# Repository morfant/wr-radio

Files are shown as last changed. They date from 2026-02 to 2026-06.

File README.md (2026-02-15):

# WR-Radio

## 설정 방법

### 1. 첫 실행
```bash
python3 wr-radio.py
```
첫 실행 시 `config.json` 파일이 자동 생성됩니다.

### 2. 스테이션 추가/변경
```bash
nano ~/wr-radio/config.json
```
```json
{
  "stations": [
    {
      "name": "내가 좋아하는 라디오",
      "url": "http://stream-url.mp3",
      "location": "Seoul, Korea",
      "lat": 37.5665,
      "lon": 126.9780,
      "color": [255, 100, 100]
    }
  ]
}
```

### 3. 날씨 기능 (선택)
1. https://openweathermap.org/appid 에서 무료 API 키 발급
2. `config.json`에 키 입력:
```json
   {
     "openweather_api_key": "여기에_키_입력"
   }
```

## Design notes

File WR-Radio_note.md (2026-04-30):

# WR-Radio 설계노트

## 프로젝트 개요
- **목적**: 전 세계 환경음을 스트리밍하는 휴대용 인터넷 라디오
- **핵심 하드웨어**: Raspberry Pi Zero 2W, ST7789 240×240 LCD, UDA1334A I2S DAC, PAM8403 앰프, ADS1115 ADC, 로터리 인코더
- **스트리밍 채널**: 제주, 런던, 뉴욕, 캘리포니아, 후지산 (5개 채널)
- **프로토타입 수량**: 약 5대

---

## 전원 시스템

### 아키텍처: TP4056 + TPS61023 분리 구성
```
USB-C → [TP4056] → LiPo 배터리 (2000~3000mAh)
                         │
                    [OUT+/OUT-]
                         │
                    [TPS61023 VIN] → 5V OUT → Pi 5V
                         │
                    EN 핀 ← 슬라이드 스위치 (GND 연결/해제)
```

- TP4056 OUT 단자 사용 (BAT+ 직결 아님) → DW01 과방전 보호 커버
- TPS61023: 3A 출력, Pi 부팅 피크 전류 헤드룸 충분
- USB 핫스왑 드롭아웃 없음 확인 (throttled=0x0)
- 슈퍼캡 불필요 (LiPo Rider Plus 때와 달리 드롭아웃 자체가 없음)

### MP2639A 불채택 사유
- TP4056로 이미 전체 검증 완료
- 1A 충전이면 야간 충전 사용 패턴에 충분
- 추가 복잡도 대비 이득 없음

### 전원 제어
- **슬라이드 스위치**: TPS61023 EN 핀을 GND에 연결/해제
- **택트 스위치**: 설계에서 제거됨 (슬라이드 스위치 단독 운용)
- **Sleep/Wake**: 제거됨 — overlayfs로 안전한 하드 전원 차단 가능

### 배터리 모니터링 (ADS1115)
- **A0**: 배터리 전압 — TPS61023 VIN에서 10kΩ/10kΩ 분압 → 소프트웨어 ×2 보정
- **A1**: VBUS 감지 — TP4056 USB VBUS 패드에서 10kΩ/10kΩ 분압
- 충전 상태 판별:
  - VBUS 있음 + BAT < 4.2V → 충전 중
  - VBUS 있음 + BAT ≈ 4.2V → 충전 완료
  - VBUS 없음 → 배터리 구동 중
- ADS1015 (12비트) 도 이 용도에는 충분 — 차기 리비전에서 비용 절감 가능

---

## PCB 설계 (Eagle CAD / Fusion 360 Electronics)

### 형태
- Pi Zero 2W와 수평 배치 (적층 아닌 옆으로 나란히)
- Pi 쪽: 직각 male 핀헤더
- PCB 쪽: 직각 female 소켓 (2x20 right angle female header)

### 높이 축소 계획
- **로우 프로파일 헤더 소켓 주문**: PH3.5mm (일반 PH8.5 대비 5mm 절감)
  - E-Simpo 1x40핀, AliExpress 주문 완료
  - 매칭 male 헤더: PH7.5mm 주문 완료
- 모듈 스태킹 검토 중 (UDA 아래 PAM8403 등) — 발열/노이즈 주의 필요

### 그라운드 설계
- 바텀 레이어: GND 폴리곤 (3개 그룹 분할)
- 탑 레이어: 여분 공간 GND 구리 푸어
- Star grounding: 아날로그/디지털 GND 한 점 합류

### 디커플링 캐패시터 (최종 목록)
- 각 모듈 VIN-GND: 100nF 세라믹 (대부분 모듈 내부 디커플링 있으므로 보험용)
- 3.3V GPIO 헤더 근처: 100nF + 10µF
- 로터리 인코더 S1/S2: 100nF 각각 (소프트웨어 디바운싱 충분하면 생략 가능)

---

## PCB 프로토타입 테스트 결과 (2026-04-30)

### ✅ 정상 동작 확인
- LCD (ST7789) 정상 표시
- 배터리 전압 모니터링 (ADS1115 A0) 정상
- VBUS 충전 상태 감지 (ADS1115 A1) 정상
- BLE 오디오 스트리밍 정상
- GND-5V 간 쇼트 없음 (캐패시터 충전으로 인한 일시적 도통만 확인 — 정상)

### ❌ BCLK 배선 오류 발견 및 수정
- **문제**: I2S BCLK가 GPIO 15에 연결됨 (정상: GPIO 18)
- **원인**: PCB 설계 시 핀 배정 오류
- **임시 수정**: 커터칼로 GPIO 15→UDA1334A BCLK 트레이스 절단, GPIO 18에서 점퍼 와이어로 연결
- **결과**: UDA1334A 오디오 출력 정상 동작
- **다음 리비전**: PCB에서 BCLK를 GPIO 18로 수정 필수
- **교훈**: Pi I2S 핀은 하드웨어 고정 — BCLK=GPIO18, LRCLK=GPIO19, DIN=GPIO21, 소프트웨어로 변경 불가

### 🔊 스피커 노이즈 분석
두 가지 노이즈 원인 확인:

**1. PAM8403 자체 노이즈 (Class-D 스위칭)**
- 이어폰 잭: 깨끗함
- 스피커: 저볼륨/무음 시 노이즈 들림, 스트리밍 중에는 묻힘
- 원인: PAM8403 고정 24dB 게인이 플로어 노이즈 증폭
- 분압 저항 기존 설치되어 있으나 불충분
- 소프트웨어 볼륨 낮추기로는 해결 불가 (앰프 자체 노이즈이므로)
- **대응**: 프로토타입에서는 감수, 차기 리비전에서 MAX98357A (I2S 직결 앰프) 교체 검토

**2. LCD SPI 노이즈**
- LCD 업데이트 시 "디기딕" 하는 추가 노이즈 발생
- SPI 고주파 노이즈가 전원 라인을 통해 오디오 쪽으로 전달
- **수정**: 메인 5V와 LCD VCC 사이에 **페라이트 비드** 직렬 삽입
  ```
  메인 5V ── [페라이트비드] ── 100nF캡 ── LCD VCC
                                  |
                                 GND
  ```
- 페라이트 비드 사양: 100Ω @ 100MHz, 정격전류 500mA 이상
- **결과**: 완전히 잡히진 않았지만 개선 효과 있음 확인
- **다음 리비전**: PCB에 페라이트 비드 정식 포함

### 기타 참고
- 다른 Pi에 기존 SD카드 이동 시 PulseAudio 캐시 충돌 가능
  - `rm -rf ~/.config/pulse && pulseaudio -k && pulseaudio --start` 로 해결
- `amixer contents` 빈 출력은 정상 (UDA1334A에 하드웨어 볼륨 컨트롤 없음)

---

## 소프트웨어

### 아키텍처
- Python 모듈 구조: main.py, display.py, player.py, config.py, state.py, input.py
- 오디오: mpv (스트리밍), BlueZ + PulseAudio (Bluetooth)
- WiFi: NetworkManager / nmcli (cloud-init/netplan에서 이전 완료)
- 디스플레이: SPI 16MHz (64MHz에서 노이즈로 인해 하향)

### 부팅 최적화
- cloud-init, ModemManager 비활성화
- 39초 → 34초로 단축
- 스플래시 이미지 + systemd 서비스 구현

### UI
- 로터리 인코더: 짧게 누르기 = 볼륨 모드, 길게 누르기 = 밝기 모드
- LCD 업데이트: 부분 화면 렌더링 (region-specific update)
- 날씨 아이콘: PIL 커스텀 드로잉 (이모지 폰트 호환 문제 해결)

---

## SD카드 보호: overlayfs (배포판 적용 예정)

- 루트 파일시스템을 읽기 전용 마운트, 변경사항은 RAM에만 기록
- 전원 갑자기 끊어도 SD카드 손상 없음
- 영구 저장 항목 (별도 `/data` 파티션): config.json, Bluetooth 페어링 정보
- 개발 중에는 OFF, 배포판 최종 이미지에서 ON

---

## 케이스 (Fusion 360)

- 파라메트릭 Python 스크립트로 자동 생성
- 보스, 리브, 마운팅 시스템, 컴포넌트별 컷아웃 포함
- 대형 배터리 + 스피커 레이아웃 최적화 중

---

## 스피커 현황

- 현재: 102mm 4Ω — 저음 왜곡 + SPI 노이즈 (PCB 이후 재평가)
- 검토 중: 30mm 캡슐 스피커, 익사이터(surface transducer)

---

## 주요 학습 사항

- 브레이크아웃 모듈은 내부 디커플링 포함 — 외부 추가는 보험용
- SPI 64MHz 노이즈가 전원/GND를 오염 → 16MHz 하향 + LCD VCC 캡 + 페라이트 비드로 완화
- PAM8403 고정 24dB 게인 → 입력 어테뉴에이션 또는 앰프 교체 필요
- UDA1334A는 라인 레벨 출력 → 이어폰 직결은 기능하지만 최적은 아님
- LCD update를 인코더 인터럽트 핸들러 안에서 하면 타이밍 간섭 → 디바운스 분리 필요
- LiPo 최적 범위 20~80%, 완전 방전 후 충전은 NiCd 시대 미신
- Pi I2S 핀은 SoC 하드웨어 고정: BCLK=GPIO18, LRCLK=GPIO19, DIN=GPIO21 — 변경 불가

---

## 향후 계획

- [x] TP4056 + TPS61023 브레드보드 검증 완료
- [x] USB 핫스왑 드롭아웃 없음 확인
- [x] 전체 부하 테스트 (Pi + DAC + 앰프 + LCD) 완료
- [x] ADS1115 배터리 전압 + VBUS 감지 구현
- [x] 부팅 시간 최적화 (39초 → 34초)
- [x] 스플래시 이미지 + systemd 서비스 구현
- [x] PCB Rev.1 제작 및 기본 동작 확인
- [x] BCLK 배선 오류 발견 및 점퍼 와이어 수정
- [x] SPI 노이즈 완화: 페라이트 비드 삽입 테스트
- [ ] **PCB Rev.2 설계** — BCLK→GPIO18 수정, 페라이트 비드 정식 포함
- [ ] 로우 프로파일 헤더 입고 후 높이 테스트 (PH3.5 소켓 + PH7.5 핀)
- [ ] 스피커 선정 확정 (PCB 이후 노이즈 재평가)
- [ ] 케이스 최종 설계 완성 + 출력
- [ ] overlayfs 설정 (배포판 단계)
- [ ] SD카드 이미지 배포판 제작 (의존성 포함)
- [ ] 사용자용 설정 가이드 문서화
- [ ] Bluetooth 헤드폰 지원 (선택적 확장)
- [ ] 마이크 입력 / 필드 레코딩 (장기)
- [ ] 앰프 교체 검토: MAX98357A (I2S 직결, UDA1334A+PAM8403 대체 가능)

---

## 주요 부품 공급처

- 디바이스마트, 아이씨뱅큐 (국내)
- Adafruit, AliExpress (해외)
- 로우 프로파일 헤더: AliExpress E-Simpo

---

*최종 업데이트: 2026-04-30 (PCB Rev.1 테스트: BCLK 배선 오류 수정, SPI 노이즈 페라이트 비드 완화, PAM8403 자체 노이즈 확인, 로우 프로파일 헤더 주문)*

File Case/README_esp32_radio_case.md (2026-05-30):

# ESP32 Portable Radio Case (Standard) — OpenSCAD

This folder contains a **parametric OpenSCAD** model for a two-part portable enclosure:
- **Base**
- **Lid (front panel)**
- **Battery door** (rear)

## Default Target
- 150 × 90 × 50 mm outer size
- 50 mm speaker (front grill)
- 0.96" OLED (SSD1306) window (toggle to 1.8" TFT if needed)
- Rotary encoder on the front
- 3.5 mm jack on the right
- Power switch on the left
- Micro‑USB slot on the back (optional toggle)
- Internal bosses/standoffs for ESP32 and small DAC/AMP boards
- Battery door fits typical 4×AA (2×2) holder

## How to Use
1. Install **OpenSCAD**.
2. Open `esp32_radio_case.scad`.
3. At the top, set `show_part` to `"base"`, render (F6), then `File → Export → STL`.
4. Repeat with `"lid"` and `"door"`.
5. Print each STL. Suggested: PETG/ABS, 0.2 mm layer, 15–25% infill, ≥3 perimeters.

## Adjustments
- Edit the **Parameters** section to match your exact modules:
  - `spk_d`, `oled_win`/`tft_win`, `enc_hole_d`, `jack_hole_d`, etc.
  - Positions: `spk_pos`, `oled_pos`/`tft_pos`, `enc_pos`, side cutouts, etc.
- Corner bosses accept **M3** (inserts or self-tapping). 
  - Hole defaults: `m3_hole` (clearance in lid), `m3_pilot` (pilot in base boss).

## Notes
- The *speaker grill* is a perforated hole pattern. Adjust `hole_r`/spacing inside `drill_grill()`.
- The **battery door** is a simple plate; you can tape/magnetize or add a tiny screw if desired.
- The file includes a basic **USB cutout**; set `usb_on_back=false` to remove.

## Next Steps
- After a first test print, measure your parts and tweak tolerances (`tol`, `lip_tol`).
- If you switch to a **1.8" TFT**, set `use_oled=false` and adjust `tft_win`/`tft_pos`.
- For very tight builds, consider moving to a custom PCB for cable reduction.

Happy printing! 🎧

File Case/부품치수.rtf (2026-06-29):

Lcd
35.5 x 70(ÀÌ Áß 20Àº ÄÉÀÌºí) x 7.5

¿£ÄÚ´õ
Áö¸§ 25 ³ôÀÌ 30(³»ºÎ) + 25(¿ÜºÎ)

½ºÇÇÄ¿
65 x 65 x 27(À¯´Ö µÎ²²)

토글 스위치
(외부 돌출 원통형 6 + 내부 박스 및 케이블 고려 20) x 13 x 7
직경 6.13mm

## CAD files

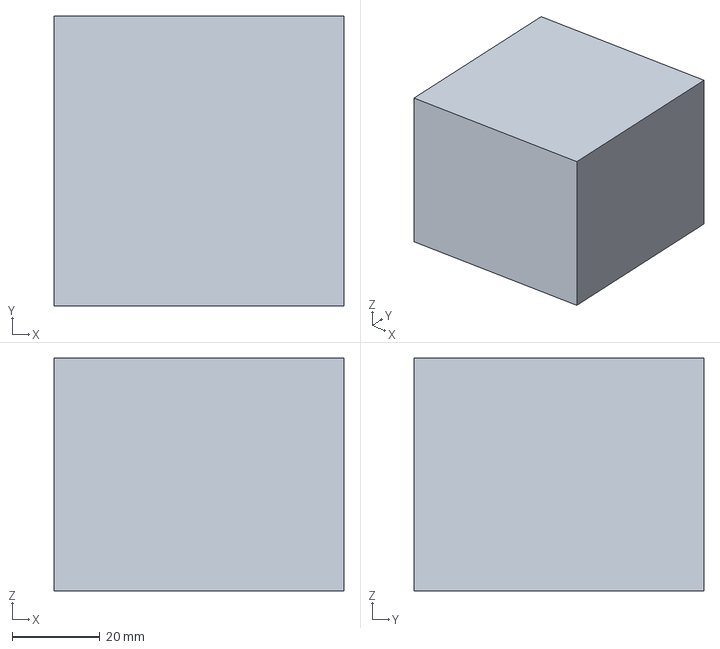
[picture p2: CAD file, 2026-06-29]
Case/envelope_speaker.step
66.0 x 66.0 x 53.0 mm

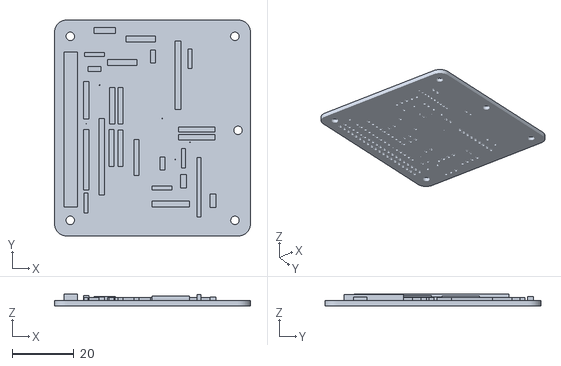
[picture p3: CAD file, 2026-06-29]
Case/radio-hat-v07.stl
63.5 x 70.0 x 3.82

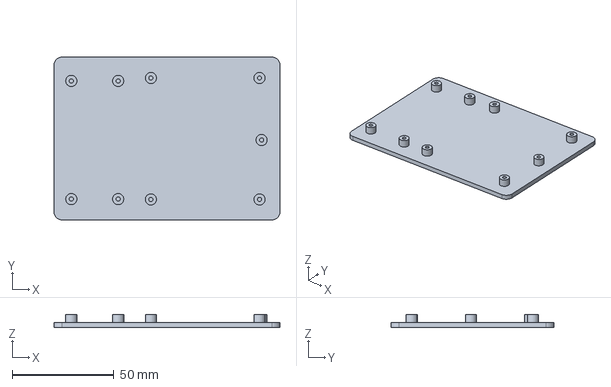
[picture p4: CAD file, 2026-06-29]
Case/wr_radio_base.step
110.9 x 80.0 x 6.50 mm

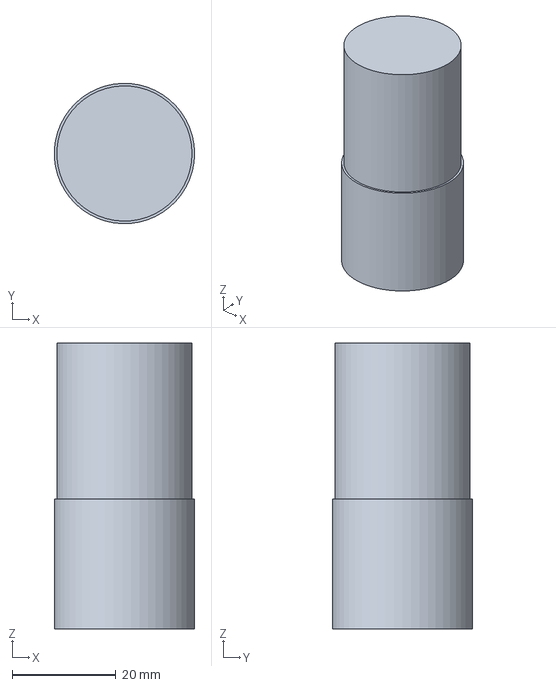
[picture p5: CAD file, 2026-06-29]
Case/envelope_encoder.step
27.0 x 27.0 x 55.0 mm

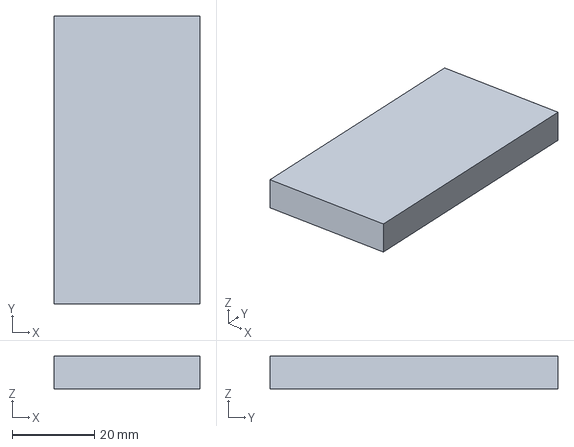
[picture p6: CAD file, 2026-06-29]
Case/envelope_lcd.step
35.5 x 70.0 x 8.00 mm

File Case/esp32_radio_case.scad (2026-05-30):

/*
ESP32 Portable Radio Case (Standard) - OpenSCAD
Author: ChatGPT
Version: 1.0
Units: millimeters

How to use:
1) Open this file in OpenSCAD.
2) Set 'show_part' = "preview" | "base" | "lid".
3) Press F6 (Render) then File → Export → STL for each part.

Printing tips (FDM):
- Material: PETG or ABS/ASA preferred (humidity tolerance). PLA ok indoors.
- Layer: 0.2 mm, walls ≥ 3 perimeters, infill 15–25%.
- No supports needed by default (chamfers/bridges are designed).
- Use heat-set M3 inserts in bosses, or self-tapping M3 screws into pilot holes.

This design targets:
- Enclosure outer size ≈ 150 × 90 × 50 (W×H×D)
- 50 mm speaker (2") front grill
- 0.96" I2C OLED (SSD1306) window OR 1.8" TFT (ST7735) window (toggleable)
- Rotary encoder on front
- 3.5 mm TRS jack on right side (panel-mount style)
- Power toggle on left side (panel cutout)
- Rear battery door (4×AA holder, 2×2 type) with simple slide latch
- Internal standoffs for: ESP32 DevKit, DAC, AMP
- M3 corner posts + lid with M3 screw holes

You may adjust parameters below to fit your exact modules. 
*/

/////////////// PARAMETERS \\\\\\\\\\\\\

show_part = "preview"; // "preview", "base", "lid", "door"

// Overall outer dimensions
W = 150;   // width (x)
H = 90;    // height (y)
D = 50;    // depth (z)

wall = 2.6;        // wall thickness
lip = 1.0;         // lid/base overlap lip
corner_r = 5;      // external fillet radius (visualized via minkowski)

// Fasteners
boss_d = 6.6;      // corner boss OD for M3 inserts/screws
boss_h = 10;       // boss height in lid/base
m3_hole = 3.2;     // through hole size for M3 (clearance)
m3_pilot = 2.6;    // pilot for self-tap (if not using inserts)

// Speaker
spk_d = 50;        // speaker driver outer diameter
spk_depth = 32;    // driver depth allowance
spk_grill_margin = 3; // grill ring margin
spk_pos = [W*0.30, H*0.62]; // (x,y) from lower-left front panel

// Display
use_oled = true;   // true: 0.96" OLED window ; false: 1.8" TFT window
// OLED 0.96" (visible area ~22x11mm, PCB ~27x27); choose window a bit larger
oled_win = [27, 15]; // window opening (w,h)
oled_pos = [W*0.62, H*0.25]; // front panel position of window center

// TFT 1.8" ST7735 option
tft_win  = [36, 46]; // opening (w,h) oriented portrait by default
tft_pos  = [W*0.62, H*0.28];

// Rotary encoder (front)
enc_hole_d = 7.2;                   // shaft/bushing hole
enc_knob_clear = 18;                // visual clearance circle
enc_pos = [W*0.62, H*0.70];         // front panel position

// 3.5mm jack (right side)
jack_hole_d = 6.6;   // panel mount diameter (adjust for your part)
jack_edge_offset = 18; // distance from front panel along X for cutout center
jack_height = H*0.35; // center height from bottom

// Power switch (left side) — simple rectangle slot
sw_slot = [10, 3];                  // opening (w,h)
sw_edge_offset = 25;                // distance from front edge to slot center
sw_height = H*0.2;                  // center height from bottom

// USB access (rear or side) — small rectangular opening (optional)
usb_slot = [13, 7]; // typical micro-USB
usb_on_back = true;
usb_back_offset = [W*0.65, H*0.18]; // center on back panel

// Battery door (rear, for 4×AA 2×2 holder ~60×60×15)
door_size = [70, 70];
door_pos  = [W*0.50, H*0.55];
door_th = 2.0;
door_clearance = 0.4;

// Internal standoffs (example positions)
standoff_h = 8;
standoff_d = 5.5;
esp32_hole = [[15,15],[45,15],[45,45],[15,45]]; // simplistic 4-hole rectangle (adjust to your DevKit!)
dac_pos = [W*0.62, H*0.52];
amp_pos = [W*0.62, H*0.40];

// Tolerances
tol = 0.3;     // general clearance
lip_tol = 0.2; // lip fit


/////////////// UTILS \\\\\\\\\\\\\

module filleted_box(size=[W,H,D], r=corner_r, center=false){
    // cheap fillet by minkowski with sphere; for preview mainly
    minkowski(){
        cube(size - [2*r,2*r,2*r], center=center);
        sphere(r, $fn=32);
    }
}

module screw_boss(h=boss_h, od=boss_d, hole=m3_hole){
    difference(){
        cylinder(h=h, r=od/2, $fn=40);
        translate([0,0,-1]) cylinder(h=h+2, r=hole/2, $fn=30);
    }
}

module grill_honeycomb(w, h, cell=4, t=1.0){
    // simple hex grid by subtracting circles (lightweight approximation)
    for (x=[-w/2+cell/2:cell:w/2-cell/2])
        for (y=[-h/2+cell/2:cell:h/2-cell/2]){
            translate([x,y,0])
                cylinder(h=t+1, r=cell*0.35, $fn=6);
        }
}

// Rounded rectangle 2D
module rrect2d(sz=[20,10], r=2){
    offset(r=r) offset(delta=-r)
        square(sz, center=true);
}

/////////////// BASE & LID \\\\\\\\\\\\\

module enclosure_base(){
    // Outer shell
    difference(){
        filleted_box([W,H,D], corner_r);
        // Hollow
        translate([wall,wall,wall])
            cube([W-2*wall, H-2*wall, D - wall - lip - lip_tol]);
        // Side cutouts (jack right)
        // right wall center at x=W, y=jack_height, z=D/2
        translate([W - wall/2, jack_height, D/2])
            rotate([0,90,0]) cylinder(h=wall+2, r=jack_hole_d/2+tol, $fn=40);

        // left wall power switch slot
        translate([wall/2, sw_height, D/2])
            rotate([0,90,0])
                linear_extrude(height=wall+2)
                    rrect2d([sw_slot[0]+tol, sw_slot[1]+tol], r=1.0);

        // USB slot on back
        if (usb_on_back){
            translate([usb_back_offset[0], H - wall/2, D/2])
                rotate([90,0,0])
                    linear_extrude(height=wall+2)
                        rrect2d([usb_slot[0]+tol, usb_slot[1]+tol], r=1.0);
        }
    }

    // Lip for lid overlap (inner ledge)
    translate([wall+lip_tol, wall+lip_tol, D - wall - lip])
        cube([W-2*(wall+lip_tol), H-2*(wall+lip_tol), lip]);

    // Corner bosses (for screws up from lid, or inserts)
    boss_z = D - wall - lip - boss_h - 1;
    for (px=[10, W-10])
      for (py=[10, H-10])
        translate([px, py, boss_z])
            screw_boss(boss_h, boss_d, m3_pilot);

    // Internal standoffs plateaus (example)
    // ESP32 area
    for (p=esp32_hole){
        translate([p[0], p[1], wall+2])
            cylinder(h=standoff_h, r=standoff_d/2, $fn=30);
    }

    // DAC/AMP shelves (simple pads)
    translate([dac_pos[0]-10, dac_pos[1]-8, wall+2])
        cube([20,16,standoff_h]);
    translate([amp_pos[0]-10, amp_pos[1]-8, wall+2])
        cube([20,16,standoff_h]);

    // Battery pocket (rear) – slight recess
    translate([door_pos[0]-door_size[0]/2, door_pos[1]-door_size[1]/2, wall+2])
        cube([door_size[0], door_size[1], 8]);
}

module enclosure_lid(){
    // Lid plate with outer fillet mimic (slightly smaller to fit)
    difference(){
        filleted_box([W-2*tol, H-2*tol, wall+lip], corner_r);
        // Underside clearance (leave rim that sits on lip)
        translate([wall,wall,0])
            cube([W-2*wall-2*tol, H-2*wall-2*tol, wall+lip]);
    }

    // Front panel features (speaker, display, encoder)
    // We "cut through" from the front face (y-plane), but since lid is a solid,
    // we subtract thin prisms to make openings.

    // Coordinate helper: front face plane at y = (H-2*tol)
    front_y = H/2; // We'll position cuts by translating to the lid and subtracting from a duplicate

    // Create cutouts by overlapping negative volumes
    difference(){
        // Nothing here; we will union cutouts then subtract at the end via separate module
    }

    // Speaker grill (through-holes in lid)
    translate([spk_pos[0], spk_pos[1], (wall+lip)/2])
        difference(){
            // Open circular aperture area
            cylinder(h=wall+lip+2, r=(spk_d/2)+spk_grill_margin, $fn=80, center=true);
            // Fill with small honeycomb voids (subtract from filler to create holes)
        }

    // Cut: actual holes for grill
    translate([spk_pos[0], spk_pos[1], 0])
        drill_grill();

    // Encoder shaft hole
    translate([enc_pos[0], enc_pos[1], -1])
        cylinder(h=wall+lip+2, r=enc_hole_d/2+tol, $fn=40);

    // Display window (choose one)
    if (use_oled){
        translate([oled_pos[0]-oled_win[0]/2, oled_pos[1]-oled_win[1]/2, -1])
            cube([oled_win[0], oled_win[1], wall+lip+2]);
    } else {
        translate([tft_pos[0]-tft_win[0]/2, tft_pos[1]-tft_win[1]/2, -1])
            cube([tft_win[0], tft_win[1], wall+lip+2]);
    }

    // Lid screw holes (match base bosses)
    for (px=[10, W-10])
      for (py=[10, H-10])
        translate([px, py, -1])
            cylinder(h=wall+lip+4, r=m3_hole/2, $fn=24);
}

module drill_grill(){
    // Make a circular cluster of holes for the speaker grill.
    // Simple pattern: radial rings of holes.
    hole_r = 2;           // hole radius
    spacing = 5;
    maxR = spk_d/2 - 4;   // leave inner margin

    for (r=[spacing:spacing:maxR])
        for (a=[0:360/max(6, floor(r/spacing)):360-1]){
            x = r*cos(a);
            y = r*sin(a);
            translate([x,y,-1])
                cylinder(h=wall+lip+4, r=hole_r, $fn=20);
        }
}
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

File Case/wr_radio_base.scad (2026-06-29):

/*
WR-Radio Base Plate (Raspberry Pi Zero 2W + radio-hat-v07) — OpenSCAD
Units: millimeters

Layout (NOT a stacked HAT): the Pi Zero 2W and the radio-hat PCB lie COPLANAR,
side by side, joined by a 90° right-angle 2x20 header. The HAT's GPIO connector
(J1) is on its LEFT edge, so the Pi sits to the LEFT of the HAT.

This file is just the BASE: a flat plate with M2.5 standoff posts under both
boards. Walls / front panel / battery bay come later.

All board dimensions and hole positions are taken from the Gerber/drill output of
PCB/radio-hat-v07_2026-06-06 (drill format METRIC TZ 000.000, FSLAX34Y34).

Usage:
  1) Open in OpenSCAD.
  2) show_part = "preview" to eyeball board alignment, "base" to export.
  3) Verify pi_gap / pi_y_offset against the physical right-angle header, tweak,
     then F6 (Render) -> File > Export > STL.
*/

/////////////// WHAT TO SHOW \\\\\\\\\\\\\

show_part = "preview";   // "preview" | "base"

/////////////// PARAMETERS \\\\\\\\\\\\\

// --- radio HAT (radio-hat-v07), origin at board bottom-left ---
hat_w = 63.48;           // board width  (x)
hat_h = 69.98;           // board height (y)
// 5x M2.5 mounting holes, gerber coords shifted +5.08 in y so board min = (0,0)
HAT_HOLES = [
    [ 5.10,  5.08],
    [58.44,  5.08],
    [ 5.12, 64.68],
    [58.42, 64.68],
    [59.44, 34.24],      // extra hole, right edge mid-height
];

// --- Raspberry Pi Zero 2W ---
pi_long  = 65;           // long edge
pi_short = 30;           // short edge
// Pi is rotated 90° CW so its long edge runs along Y and the GPIO header faces
// the HAT (+x). It is placed to the LEFT of the HAT.
pi_gap      = 7.45;      // gap between Pi right edge and HAT left edge — measured: 7.3 (bottom) / 7.6 (top), avg 7.45
pi_y_offset = 1.75;      // shift Pi along Y to align header with J1 — measured offset ~0.75mm down from 2.5

// derived Pi placement (do not edit; driven by the two params above)
pi_x0 = -(pi_short + pi_gap);   // Pi bounding-box min x
pi_y0 = pi_y_offset;            // Pi bounding-box min y
// Pi M2.5 holes (58x23 pattern, 3.5 mm from each edge) in base coords
PI_HOLES = [
    [pi_x0 + 3.5,  pi_y0 + 3.5],
    [pi_x0 + 3.5,  pi_y0 + 61.5],
    [pi_x0 + 26.5, pi_y0 + 3.5],
    [pi_x0 + 26.5, pi_y0 + 61.5],
];

// --- base plate ---
base_th   = 2.5;         // plate thickness
margin    = 5.0;         // extra plate border beyond board footprints
corner_r  = 4.0;         // base outer fillet
post_h    = 4.0;         // standoff height (lifts boards off the plate)
post_od   = 5.5;         // standoff outer diameter
screw_d   = 2.1;         // pilot hole for M2.5 self-tapping screw (use 2.6 for inserts)
screw_depth = post_h + base_th;   // how deep the pilot goes

$fn = 48;

/////////////// DERIVED EXTENTS \\\\\\\\\\\\\

// footprint bounds across both boards
min_x = pi_x0 - margin;
max_x = hat_w + margin;
min_y = min(0, pi_y0) - margin;
max_y = max(hat_h, pi_y0 + pi_long) + margin;
plate_w = max_x - min_x;
plate_h = max_y - min_y;

/////////////// MODULES \\\\\\\\\\\\\

module rrect(sz, r) {
    offset(r=r) offset(delta=-r) square(sz, center=false);
}

module standoff(pos) {
    translate([pos[0], pos[1], 0]) {
        difference() {
            cylinder(h = base_th + post_h, d = post_od);
            translate([0, 0, base_th + post_h - screw_depth + 0.01])
                cylinder(h = screw_depth, d = screw_d);
        }
    }
}

module base_plate() {
    // plate
    translate([min_x, min_y, 0])
        linear_extrude(base_th)
            rrect([plate_w, plate_h], corner_r);
    // standoffs
    for (p = HAT_HOLES) standoff(p);
    for (p = PI_HOLES)  standoff(p);
}

// --- preview-only board ghosts (sit on top of the standoffs) ---
module hat_ghost() {
    color([0.2, 0.5, 0.9, 0.35])
        translate([0, 0, base_th + post_h])
            linear_extrude(1.6)
                difference() {
                    square([hat_w, hat_h]);
                    for (p = HAT_HOLES) translate(p) circle(d = 2.75);
                }
}

module pi_ghost() {
    color([0.2, 0.8, 0.4, 0.35])
        translate([pi_x0, pi_y0, base_th + post_h])
            linear_extrude(1.6)
                difference() {
                    square([pi_short, pi_long]);
                    for (p = PI_HOLES) translate([p[0]-pi_x0, p[1]-pi_y0]) circle(d = 2.75);
                }
    // GPIO header block on the Pi edge facing the HAT (visual only)
    color([0.1, 0.1, 0.1, 0.5])
        translate([pi_x0 + pi_short - 5, pi_y0 + (pi_long-50.8)/2, base_th + post_h + 1.6])
            cube([5, 50.8, 8.5]);
}

/////////////// OUTPUT \\\\\\\\\\\\\

if (show_part == "base") {
    base_plate();
} else {
    base_plate();
    hat_ghost();
    pi_ghost();
}

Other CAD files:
Case/envelope_encoder.stl
Case/envelope_lcd.stl
Case/envelope_speaker.stl
Case/wr_radio_base.dxf
Case/wr_radio_base.stl

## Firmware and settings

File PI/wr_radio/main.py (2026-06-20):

#!/usr/bin/env python3
# -*- coding: utf-8 -*-

from PIL import ImageDraw, ImageFont
import os
import signal
import sys
import time

import RPi.GPIO as GPIO
import spidev
from PIL import Image

from .state import AppState
from . import config
from .config import setup_config_interactive, save_settings
from . import player
from . import weather
from . import display
from .input import InputConfig, ButtonState, read_rotary, handle_button
from .battery import BatteryMonitor
from . import bluetooth
from . import wifi
from . import webadmin

LOCK_FILE = "/tmp/wr_radio.lock"

# BCM pins
PIN_S1 = 17
PIN_S2 = 27
PIN_KEY = 22

PIN_CS = 26
PIN_DC = 13
PIN_RST = 6
PIN_BL = 12

# 시스템 메뉴 항목
SYSTEM_MENU_ITEMS = [
    {"label": "Brightness",       "action": "brightness"},
    {"label": "Bluetooth",        "action": "bluetooth"},
    {"label": "Manage Stations",  "action": "station_admin"},
    {"label": "WiFi Setup",       "action": "wifi_setup"},
    {"label": "Power Off",        "action": "shutdown"},
    {"label": "Back",             "action": "back"},
]

# 폰트 경로
FONT_PATH = "/usr/share/fonts/truetype/dejavu/DejaVuSans-Bold.ttf"
FONT_PATH_REGULAR = "/usr/share/fonts/truetype/dejavu/DejaVuSans.ttf"


def load_font(size: int, bold: bool = False) -> ImageFont.FreeTypeFont:
    try:
        path = FONT_PATH if bold else FONT_PATH_REGULAR
        return ImageFont.truetype(path, size)
    except Exception:
        return ImageFont.load_default()


def acquire_lock():
    if os.path.exists(LOCK_FILE):
        try:
            with open(LOCK_FILE, "r") as f:
                pid = int((f.read() or "0").strip())
            if pid > 0:
                os.kill(pid, 0)
                print(f"❌ 이미 실행 중입니다 (pid={pid}).")
                sys.exit(1)
        except ProcessLookupError:
            pass
        except Exception:
            pass

    with open(LOCK_FILE, "w") as f:
        f.write(str(os.getpid()))


def release_lock():
    try:
        if os.path.exists(LOCK_FILE):
            os.remove(LOCK_FILE)
    except Exception:
        pass


def pwm_safe_close(state: AppState):
    try:
        if state.pwm_backlight is not None:
            try:
                state.pwm_backlight.stop()
            except Exception:
                pass
            try:
                del state.pwm_backlight
            except Exception:
                pass
    finally:
        state.pwm_backlight = None


def set_brightness(state: AppState, level: int, bl_pin: int) -> int:
    level = max(10, min(100, level))
    if state.pwm_backlight is None:
        state.pwm_backlight = GPIO.PWM(bl_pin, 1000)
        state.pwm_backlight.start(level)
        state.current_brightness = level
        return level
    try:
        state.pwm_backlight.ChangeDutyCycle(level)
        state.current_brightness = level
        return level
    except Exception:
        pwm_safe_close(state)
        state.pwm_backlight = GPIO.PWM(bl_pin, 1000)
        state.pwm_backlight.start(level)
        state.current_brightness = level
        return level


def draw_system_menu(state: AppState, selected_index: int) -> Image.Image:
    """시스템 메뉴 화면 렌더링"""
    img = Image.new("RGB", (240, 240), (0, 0, 0))
    draw = ImageDraw.Draw(img)

    font_title = load_font(13, bold=False)
    font_item  = load_font(15, bold=False)

    # 타이틀
    draw.text((20, 18), "System", fill=(80, 80, 100), font=font_title)
    draw.line([(20, 38), (220, 38)], fill=(40, 40, 50), width=1)

    # 메뉴 항목 — 항목 수에 따라 간격 자동 조정
    n = len(SYSTEM_MENU_ITEMS)
    start_y = 50
    item_h = min(40, (240 - start_y) // n)

    for i, item in enumerate(SYSTEM_MENU_ITEMS):
        y = start_y + i * item_h
        is_selected = (i == selected_index)

        if is_selected:
            draw.rounded_rectangle([(16, y - 1), (224, y + item_h - 3)],
                                   radius=6, fill=(25, 25, 40))
            label_color = (230, 230, 255)
        else:
            label_color = (100, 100, 120)

        draw.text((32, y + max(2, (item_h - 18) // 2)),
                  item["label"], fill=label_color, font=font_item)

    return img


def draw_brightness_menu(state: AppState) -> Image.Image:
    """밝기 조절 화면"""
    img = Image.new("RGB", (240, 240), (0, 0, 0))
    draw = ImageDraw.Draw(img)

    font_title = load_font(13, bold=False)
    font_value = load_font(22, bold=False)

    draw.text((20, 18), "Brightness", fill=(80, 80, 100), font=font_title)
    draw.line([(20, 38), (220, 38)], fill=(40, 40, 50), width=1)
    draw.text((120, 120), f"{state.current_brightness}%", fill=(230, 230, 255), font=font_value, anchor="mm")

    return img


def return_to_normal(state: AppState, gpio_pins: dict, radio_stations: list, current_index: int):
    """시스템 메뉴에서 normal 복귀 시 화면 완전 초기화 후 재렌더"""
    try:
        blank = Image.new("RGB", (240, 240), (0, 0, 0))
        display.display_image(GPIO, {"CS": gpio_pins["CS"], "DC": gpio_pins["DC"]}, state, blank)
    except Exception:
        pass
    wd = weather.get_cached_weather(state, radio_stations[current_index]["lat"], radio_stations[current_index]["lon"])
    display.display_radio_info(GPIO, {"CS": gpio_pins["CS"], "DC": gpio_pins["DC"]}, state, weather_data=wd, force_full=True)
    state.last_displayed_weather = wd


def reload_stations(state: AppState, pins: dict):
    """웹 관리로 변경된 config.json을 메인 스레드에서 안전하게 반영.
    state.radio_stations / current_index는 오직 여기(메인 스레드)서만 수정된다."""
    state.stations_dirty = False   # 먼저 끔: reload 중 들어온 추가 변경은 다음 루프가 처리
    new = config.load_config()
    if not new or not new.get("stations"):
        return
    stations = config.normalize_stations(new["stations"])

    playing_url = None
    if state.is_playing and 0 <= state.current_index < len(state.radio_stations):
        playing_url = state.radio_stations[state.current_index].get("url")

    state.radio_stations = stations

    if playing_url is not None:
        # 재생 중이던 스테이션을 url로 추적 → 앞 항목 삭제/순서변경에도 끊김 없음
        match = next((k for k, s in enumerate(stations)
                      if s.get("url") == playing_url), None)
        if match is not None:
            state.current_index = match
        else:
            # 재생 중이던 스테이션이 삭제/URL변경됨 → 클램프 후 새 스테이션 재생
            state.current_index = max(0, min(state.current_index, len(stations) - 1))
            state.pending_play = True
            state.last_station_change_time = time.time()
    else:
        state.current_index = max(0, min(state.current_index, len(stations) - 1))

    # 화면/날씨 캐시 강제 리프레시
    state.last_displayed_index = -1
    state.last_updated_index = -1
    state.last_displayed_weather = None
    if state.current_mode == "normal":
        return_to_normal(state, pins, state.radio_stations, state.current_index)
    print(f"📻 스테이션 목록 갱신: {len(stations)}개 (현재 {state.current_index + 1})")


def get_admin_url() -> str:
    """관리 페이지 접속 URL. mDNS 호스트명(<host>.local) 우선, 실패 시 라우팅 IP."""
    import socket
    try:
        host = socket.gethostname()
        if host:
            return f"{host}.local:{webadmin.PORT}"
    except Exception:
        pass
    try:
        s = socket.socket(socket.AF_INET, socket.SOCK_DGRAM)
        s.connect(("8.8.8.8", 80))
        ip = s.getsockname()[0]
        s.close()
        return f"{ip}:{webadmin.PORT}"
    except Exception:
        return f"localhost:{webadmin.PORT}"


def show_station_admin(state: AppState, pins: dict):
    """LCD에 관리 페이지 URL을 표시하고 노브를 누르면 종료.
    웹서버는 상시 동작하므로 이 화면은 단순히 주소 안내용이다."""
    url = get_admin_url()
    print(f"🌐 Manage Stations: http://{url}")
    display.display_station_admin_url(GPIO, pins, state, url)
    key_pin = pins["KEY"]
    # 진입 시 메뉴 선택 버튼이 떼어질 때까지 대기 (잔류 입력 무시)
    while GPIO.input(key_pin) == 0:
        time.sleep(0.02)
    # 다음 누름 대기 → 떼임 대기 후 종료
    while GPIO.input(key_pin) == 1:
        time.sleep(0.02)
    while GPIO.input(key_pin) == 0:
        time.sleep(0.02)


def do_shutdown(state: AppState, gpio_pins: dict):
    """설정 저장 → LCD 메시지 → mpv 종료 → halt"""
    print("\n🔴 종료 시작...")

    if state.needs_save:
        save_settings(state.current_index, state.current_volume, state.current_brightness)
        state.needs_save = False

    try:
        img = Image.new("RGB", (240, 240), (0, 0, 0))
        draw = ImageDraw.Draw(img)
        font = load_font(16, bold=False)
        draw.text((120, 100), "Shutting down...", fill=(140, 140, 160), font=font, anchor="mm")
        draw.text((120, 135), "Wait 15 sec before", fill=(200, 60, 60), font=font, anchor="mm")
        draw.text((120, 158), "switching off", fill=(200, 60, 60), font=font, anchor="mm")
        display.display_image(GPIO, {"CS": gpio_pins["CS"], "DC": gpio_pins["DC"]}, state, img)
    except Exception:
        pass

    time.sleep(3.0)

    try:
        player.stop_playback(state)
    except Exception:
        pass

    # BT 연결 해제
    if state.bt_mac:
        try:
            bluetooth.disconnect(state.bt_mac)
            state.bt_mac  = ""
            state.bt_sink = ""
        except Exception:
            pass

    try:
        img = Image.new("RGB", (240, 240), (0, 0, 0))
        display.display_image(GPIO, {"CS": gpio_pins["CS"], "DC": gpio_pins["DC"]}, state, img)
    except Exception:
        pass

    os.system("sudo halt")


def _show_bt_msg(state: AppState, gpio_pins: dict, msg: str, color: tuple):
    img  = Image.new("RGB", (240, 240), (0, 0, 0))
    draw = ImageDraw.Draw(img)
    draw.text((20, 18), "Bluetooth", fill=(80, 80, 100), font=load_font(13))
    draw.line([(20, 38), (220, 38)], fill=(40, 40, 50), width=1)
    for i, line in enumerate(msg.split("\n")):
        draw.text((120, 110 + i * 28), line, fill=color,
                  font=load_font(15), anchor="mm")
    display.display_image(GPIO, {"CS": gpio_pins["CS"], "DC": gpio_pins["DC"]},
                          state, img)


def _bt_connect(state: AppState, gpio_pins: dict,
                mac: str, name: str, is_paired: bool) -> bool:
    # 기존 연결 정보 저장 (실패 시 복구용)
    prev_mac  = state.bt_mac  if state.bt_mac != mac else ""

    if not is_paired:
        _show_bt_msg(state, gpio_pins, f"Pairing...\n{name[:20]}", (255, 200, 80))
        if not bluetooth.pair(mac):
            _show_bt_msg(state, gpio_pins, "Pairing failed", (200, 80, 80))
            time.sleep(2.0)
            _bt_ensure_output(state, gpio_pins, prev_mac)
            return False

    _show_bt_msg(state, gpio_pins, f"Connecting...\n{name[:20]}", (255, 200, 80))
    if not bluetooth.connect(mac):
        _show_bt_msg(state, gpio_pins, "Connect failed", (200, 80, 80))
        time.sleep(2.0)
        _bt_ensure_output(state, gpio_pins, prev_mac)
        return False

    sink = bluetooth.find_bt_sink()
    if not sink:
        _show_bt_msg(state, gpio_pins, "Sink not found", (200, 80, 80))
        bluetooth.disconnect(mac)
        time.sleep(2.0)
        _bt_ensure_output(state, gpio_pins, prev_mac)
        return False

    # 성공 → 기존 연결 해제 후 sink 재확인
    if prev_mac:
        bluetooth.disconnect(prev_mac)
        time.sleep(0.5)
        # 기존 sink가 사라졌으니 새 sink 다시 탐색
        sink = bluetooth.find_bt_sink(retries=4, wait=0.5)
        if not sink:
            _show_bt_msg(state, gpio_pins, "Sink lost", (200, 80, 80))
            time.sleep(2.0)
            _bt_ensure_output(state, gpio_pins, "")
            return False

    state.bt_mac      = mac
    state.bt_sink     = sink
    state.output_mode = "bluetooth"
    was_playing = state.is_playing
    player.stop_playback(state)
    player.restart_mpv(state)
    if was_playing:
        player.play_station(state, state.current_index)
    _show_bt_msg(state, gpio_pins, f"Connected\n{name[:20]}", (100, 200, 100))
    time.sleep(1.5)
    return True


def _bt_ensure_output(state: AppState, gpio_pins: dict, prev_mac: str):
    """
    연결 실패 후 출력 복구.
    - 이전 BT 장치가 살아있으면 그대로 유지
    - 아니면 스피커로 fallback
    """
    was_playing = state.is_playing

    # 이전 BT 장치 확인
    if prev_mac and bluetooth.is_device_connected(prev_mac):
        sink = bluetooth.get_current_bt_sink()
        if sink:
            # 기존 BT 연결 정상 → 유지
            state.bt_mac      = prev_mac
            state.bt_sink     = sink
            state.output_mode = "bluetooth"
            return

    # 이전 연결도 없음 → 스피커 fallback
    state.output_mode = "speaker"
    state.bt_mac      = ""
    state.bt_sink     = ""
    player.stop_playback(state)
    player.restart_mpv(state)
    if was_playing:
        player.play_station(state, state.current_index)


def _bt_disconnect(state: AppState, gpio_pins: dict):
    _show_bt_msg(state, gpio_pins, "Disconnecting...", (180, 180, 180))
    bluetooth.disconnect(state.bt_mac)
    state.output_mode = "speaker"
    state.bt_mac = state.bt_sink = ""
    was_playing = state.is_playing
    player.stop_playback(state)
    player.restart_mpv(state)
    if was_playing:
        player.play_station(state, state.current_index)
    _show_bt_msg(state, gpio_pins, "Disconnected", (100, 200, 100))
    time.sleep(1.2)


def _draw_bt_list(state, devices, selected, scanning, scan_elapsed):
    SCAN_DURATION = 15
    img  = Image.new("RGB", (240, 240), (0, 0, 0))
    draw = ImageDraw.Draw(img)
    ft   = load_font(13)
    fi   = load_font(14)
    fs   = load_font(11)

    draw.text((20, 18),
              "Bluetooth" + ("  Scanning..." if scanning else ""),
              fill=(80, 80, 100), font=ft)
    draw.line([(20, 38), (220, 38)], fill=(40, 40, 50), width=1)
    if scanning:
        bw = int(200 * min(scan_elapsed, SCAN_DURATION) / SCAN_DURATION)
        draw.rectangle([(20, 34), (20 + bw, 37)], fill=(60, 100, 180))

    scan_label = "  Scanning..." if scanning else "  Scan for devices"
    specials   = [scan_label]
    if state.bt_mac:
        specials.append("  Disconnect")
    specials.append("  Back")
    all_items = devices + specials

    item_h  = 36
    start_y = 48
    visible = 5
    offset  = max(0, selected - visible + 1)

    for slot, item in enumerate(all_items[offset: offset + visible]):
        ridx = slot + offset
        y    = start_y + slot * item_h
        sel  = (ridx == selected)
        if sel and not scanning:
            draw.rounded_rectangle([(16, y), (224, y + 28)],
                                   radius=5, fill=(25, 25, 40))
        if isinstance(item, tuple):
            mac, name, paired = item
            conn  = (mac == state.bt_mac)
            dot   = (100, 160, 255) if conn else (70, 70, 90) if paired else (50, 50, 50)
            if scanning:
                dot = tuple(c // 3 for c in dot)
            draw.ellipse([22, y+9, 30, y+17], fill=dot)
            if scanning:
                nc = (60, 60, 70)
            elif sel:
                nc = (230, 230, 255)
            else:
                nc = (160, 160, 200)
            draw.text((36, y+5), name[:22], fill=nc, font=fi)
            if not paired and not scanning:
                draw.text((198, y+5), "New", fill=(100, 200, 100), font=fs)
        else:
            if scanning:
                c = (50, 50, 50)   # 스캔 중 특수 항목도 dim
            elif "Disconnect" in item:
                c = (255, 120, 120) if sel else (180, 80, 80)
            elif "Scan" in item:
                c = (200, 200, 100) if sel else (120, 120, 60)
            else:
                c = (180, 180, 200) if sel else (100, 100, 120)
            draw.text((20, y+5), item, fill=c, font=fi)

    total = len(all_items)
    if total > visible:
        bh  = max(10, int(190 * visible / total))
        by  = 48 + int(190 * offset / total)
        draw.rectangle([(235, 48), (237, 238)], fill=(30, 30, 30))
        draw.rectangle([(235, by), (237, by + bh)], fill=(80, 80, 100))

    return img


def do_bluetooth(state: AppState, gpio_pins: dict):
    SCAN_DURATION  = 15    # 초
    POST_SCAN_WAIT = 8     # 스캔 종료 후 이름 조회 대기 (초)
    REFRESH_SEC    = 0.5
    DEBOUNCE       = 0.02
    pins_disp = {"CS": gpio_pins["CS"], "DC": gpio_pins["DC"]}

    scanner      = None
    scanning     = False
    scan_start   = 0.0
    scan_ended   = 0.0    # 스캔 종료 시각 (0=종료 안 됨)
    selected     = 0
    last_refresh = 0.0
    scan_was_playing = False  # 스캔 시작 전 재생 상태

    devices = [(mac, name, True)
               for mac, name in bluetooth.get_paired_devices()]

    if state.bt_mac:
        for i, (mac, _, _) in enumerate(devices):
            if mac == state.bt_mac:
                selected = i
                break

    def specials():
        s = ["  Scanning..." if scanning else "  Scan for devices"]
        if state.bt_mac:
            s.append("  Disconnect")
        s.append("  Back")
        return s

    def all_items():
        return devices + specials()

    def render():
        el  = (time.time() - scan_start) if scanning else 0
        img = _draw_bt_list(state, devices, selected, scanning, el)
        display.display_image(GPIO, pins_disp, state, img)

    render()

    s1_last  = GPIO.input(gpio_pins["S1"])
    key_last = GPIO.input(gpio_pins["KEY"])
    last_rot = time.time()

    try:
        while True:
            now = time.time()

            # ── 스캔 중: 진행 바만 갱신, 입력 무시 ────────
            if scanning:
                elapsed = now - scan_start
                if elapsed >= SCAN_DURATION:
                    scanner.stop()
                    scanning   = False
                    scan_ended = now
                    devices[:] = scanner.get_devices()
                    render()
                elif (now - last_refresh) >= REFRESH_SEC:
                    devices[:] = scanner.get_devices()
                    render()
                    last_refresh = now
                # 입력 상태만 읽어서 버림 (눌림 누적 방지)
                s1_last  = GPIO.input(gpio_pins["S1"])
                key_last = GPIO.input(gpio_pins["KEY"])
                time.sleep(0.05)
                continue

            # ── grace period: 이름 조회 완료 대기 ──────────
            elif scan_ended and scanner:
                if (now - last_refresh) >= REFRESH_SEC:
                    devices[:] = scanner.get_devices()
                    render()
                    last_refresh = now
                if not scanner.has_pending() or (now - scan_ended) >= POST_SCAN_WAIT:
                    devices[:] = scanner.get_devices()
                    render()
                    scanner    = None
                    scan_ended = 0.0
                    if scan_was_playing:
                        player.play_station(state, state.current_index)
                        scan_was_playing = False

            # ── 로터리 ─────────────────────────────────────
            s1 = GPIO.input(gpio_pins["S1"])
            s2 = GPIO.input(gpio_pins["S2"])
            if s1 == 0 and s1_last == 1 and (now - last_rot) > DEBOUNCE:
                direction = -1 if s2 == 1 else 1
                selected  = (selected + direction) % len(all_items())
                last_rot  = now
                render()
            s1_last = s1

            # ── 버튼 ───────────────────────────────────────
            key = GPIO.input(gpio_pins["KEY"])
            if key == 1 and key_last == 0:
                items = all_items()
                item  = items[selected]

                if isinstance(item, tuple):
                    mac, name, is_paired = item
                    if scanner:
                        scanner.stop()
                        scanning = False
                        scanner  = None
                    if mac == state.bt_mac:
                        _bt_disconnect(state, gpio_pins)
                    else:
                        _bt_connect(state, gpio_pins, mac, name, is_paired)
                    break

                elif "Scan" in item and not scanning:
                    if scanner:
                        scanner.stop()
                    # 스캔 중 오디오 정지 (BT 간섭 방지)
                    scan_was_playing = state.is_playing
                    if scan_was_playing:
                        player.stop_playback(state)
                    scanner      = bluetooth.Scanner()
                    scanning     = True
                    scan_start   = now
                    scan_ended   = 0.0
                    last_refresh = 0.0
                    scanner.start()
                    print("🔵 BT 스캔 시작")

                elif "Disconnect" in item:
                    if scanner:
                        scanner.stop()
                        scanning = False
                        scanner  = None
                    _bt_disconnect(state, gpio_pins)
                    break

                elif "Back" in item:
                    break

            key_last = key
            time.sleep(0.005)

    finally:
        if scanner:
            scanner.stop()
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

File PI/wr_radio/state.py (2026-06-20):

from __future__ import annotations
from dataclasses import dataclass, field
from typing import Any, Dict, List, Optional, Tuple

@dataclass
class AppState:
    # config / stations
    radio_stations: List[Dict[str, Any]] = field(default_factory=list)
    current_index: int = 0

    # runtime flags
    is_playing: bool = False
    current_mode: str = "normal"  # 'normal', 'volume', 'brightness', 'system_menu'

    # mode values
    current_volume: int = 50
    current_brightness: int = 100
    mode_enter_time: float = 0.0

    # weather
    enable_weather: bool = False
    openweather_api_key: str = ""
    weather_cache: Dict[str, Tuple[float, Dict[str, int]]] = field(default_factory=dict)

    # display cache
    last_displayed_index: int = -1
    last_displayed_playing: Optional[bool] = None
    animation_frame: int = 0
    animation_cleared: bool = False

    # audio monitoring
    audio_playing: bool = False
    shutting_down: bool = False

    # battery
    battery_monitor: Any = None
    last_battery_percent: int = -1

    # weather display
    last_displayed_weather: Any = None

    # save
    needs_save: bool = False
    last_change_time: float = 0.0

    # pending actions
    pending_play: bool = False
    last_station_change_time: float = 0.0

    # 웹 관리에서 스테이션 목록이 바뀌면 True. 메인 루프가 안전한 시점에 reload 후 클리어.
    stations_dirty: bool = False

    # input bookkeeping
    last_input_time: float = 0.0
    last_updated_index: int = -1

    # handles
    spi: Any = None
    pwm_backlight: Any = None
    player_process: Any = None

    # mpv socket path
    mpv_sock: str = "/tmp/wr_mpv.sock"

    # ── Bluetooth ──────────────────────────────────────────
    # 현재 출력 모드: "speaker" | "bluetooth"
    output_mode: str = "speaker"
    # 연결된 BT 장치 MAC (연결 중일 때만 값 있음)
    bt_mac: str = ""
    # PulseAudio BT sink 이름 (연결 중일 때만 값 있음)
    bt_sink: str = ""

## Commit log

2026-02-15 edit encoder pin out
2026-02-20 LCD pin change
2026-02-25 Display battery status, Fix weather update timing
    [battery.py, charging_test.py, display.py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]
2026-02-26 Earphone insert check system
2026-02-28 Pam 모듈 교체 후 음량 테스트
2026-02-28 LCD SPI update interval change (1.0)
2026-03-02 Fix pin numbers on lcd_test.py
    [lcd_test.py]
2026-03-04 Menu 정리
2026-03-04 첫 시작시 배터리 측정 오류 수정
    [battery.py]
2026-03-06 BT 기본 기능 구현
2026-03-06 BT 기능 개선
2026-03-07 BT scan 기능 확인
2026-03-21 BT 연결 안정성 개선
    - A2DP 장치만 필터링 (UUID 0x110b 확인)
    - BT sink 연결 끊김 자동 감지 → 스피커 전환
    - 이름 없는 장치/MAC 형태 이름 제외
2026-03-21 스플래시 화면 + systemd 서비스 등록
    - 부팅 시 LCD에 스플래시 이미지 표시 (assets/splash.png)
    - wr-radio.service로 부팅 시 자동 시작 (NetworkManager 이후)
    - rc.local의 boot_greeting.py 주석 처리
2026-03-21 스플래시 화면 표시 + BT 연결 복구 로직 개선
    - LCD 초기화 직후 스플래시 이미지 표시 (다른 초기화 전)
    - 라디오 UI 전환 시 전체 화면 클리어 (스플래시 잔상 제거)
    - BT 연결 실패 시 이전 출력 복구 로직 추가
    - BT 종료 시 연결 해제 처리
    - 충전 상태 변경 시 배터리 아이콘 즉시 갱신 (1초)
2026-03-21 USB VBUS 충전 감지 + 배터리 아이콘 충전 표시
    - ADS1115 A0: 배터리 전압, A1: USB VBUS 전압 (충전 감지)
    - VBUS 2초마다 체크, 배터리 전압 10초마다 체크
    - 충전 시 배터리 아이콘에 번개 표시
    - 충전 상태 변경 로그 출력
2026-03-21 SIGTERM 클린 셧다운 + BT 부팅 감지 개선
    - SIGTERM 핸들러 추가 (systemd stop/halt 시 정리 작업 실행)
    - BT 감지를 mpv 시작 전으로 이동 (처음부터 BT sink로 시작)
    - systemd 서비스에 PulseAudio 환경 변수 추가 (XDG_RUNTIME_DIR, DBUS)
    - BT 끊김 시 LCD 강제 갱신 (BT 아이콘 제거)
    - finally에서 BT disconnect 제거 (restart 시 BT 연결 유지)
2026-04-02 Add PCB files
    [wr-radio-hat.brd, wr-radio-hat.sch]
2026-04-30 Add PCB CAM/Gerber outputs and exclude .DS_Store from git
    [copper_bottom.gbr, copper_top.gbr, drill_1_64.xln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]
2026-04-30 PCB v0.5 수정 후 작동 확인, note 업데이트
2026-05-30 Restructure repo: move PI code under PI/, add CLAUDE.md, add PCB v0.5 files
    - wr_radio/, run.py, test/, assets/ → PI/ 하위로 이동 (디렉토리 구조 정리)
    - CLAUDE.md 추가 (소프트웨어 아키텍처, GPIO 핀 배정, 실행 방법 문서화)
    - PCB/radio-hat_2026-05-21 Gerber 파일 추가
    - Case/ OpenSCAD 케이스 파일 추가
    [av-streamer-led-hat.brd, av-streamer-led-hat.sch, esp32_radio_case.scad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]
2026-05-30 Fix: 시간 표시 분 단위 자동 갱신
    채널 변경 없이도 1분마다 시간 텍스트 영역(y=68 strip)만 부분 업데이트.
    전체 화면 재렌더 대신 display_time_only()로 SPI 트래픽 최소화.
    [display.py, main.py]
2026-05-30 Fix: 충전 중 번개 볼트가 배터리 외곽선 밖으로 삐져나오는 문제 수정
    볼트 좌표를 y+1~y+13 → y+3~y+11로 조정해 배터리 내곽에 맞춤.
    [display.py]
2026-05-30 Fix: 배터리 아이콘 가로 폭 축소 (24px → 20px)
    본체 24→20, 팁 위치 24→20, 최대 fill 22→18px, 볼트 좌표 비례 조정.
    [display.py]
2026-05-30 Add weather icon test: 3×3 그리드로 전체 아이콘 표시
2026-05-30 Fix: mist/fog 아이콘 개선 — 줄 길이·위치 변화로 안개 느낌
    [display.py]
2026-05-30 Fix: fog 아이콘 — 뒤집힌 구름 형태로 개선 (위 평평, 아래 뭉게뭉게)
    [display.py]
2026-05-30 Fix: drizzle(09) 아이콘 — 점선 2줄로 개선, rain(10)과 분리
    [display.py]
2026-05-30 Fix: overcast(04) 아이콘 — 작은 구름 두 개 나란히, clouds(03)와 분리
    [display.py]
2026-05-30 Fix: mist(50) 아이콘 — 작은 원 5개 살짝 겹쳐 가로 나열
    [display.py]
2026-05-30 Fix: overcast(04) 구름 3타원 구조로, drizzle(09) 점으로, mist(50) 크기/위치 불규칙
    [display.py]
2026-05-30 Fix: overcast 구름 크기 확대, drizzle 점 3개, mist 작은 원 6개 넓게 산포
    [display.py]
2026-05-30 Fix: overcast(04) — 풀사이즈 구름 두 개 15px 오프셋으로 겹침
    [display.py]
2026-05-30 Add weather layout test: 실제 display_radio_info 레이아웃으로 아이콘+온도 확인
2026-05-30 Fix: 온도 텍스트 오프셋 28→40px (overcast 아이콘 겹침 해소)
    [display.py]
2026-05-30 Update weather_layout_test: 모든 아이콘 5초 간격 순환
2026-05-30 Fix: 날씨 아이콘+온도 위치 icon_x 90→80 (화면 중앙 정렬)
    [display.py]
2026-05-30 Fix: 날씨 아이콘 레이아웃 정리 — 04/03 합치기, 가운데 정렬, 세로 정렬
    - overcast(04) → clouds(03)와 동일 처리
    - icon_x 80→86, 온도 오프셋 40→30 (간격 좁히고 중앙 정렬)
    - icon_y +40→+43 (온도 텍스트와 세로 정렬)
    [display.py]
2026-05-30 Fix: mist(50) 아이콘 — 파란 점 6개로 변경 (drizzle과 동일 색상, 넓게 산포)
    [display.py]
2026-05-30 Fix: mist(50) 아래쪽에 파란 점 4개 추가
    [display.py]
2026-05-30 Update CLAUDE.md: 테스트 스크립트, 디스플레이 레이아웃, Pi 배포 정보 추가
2026-05-30 Add WiFi provisioning: AP mode + browser setup page
    - wifi.py: NM hotspot, network scan, HTTP server (stdlib), connect flow
    - display.py: provisioning screen, connecting/success/failed states
    - main.py: startup WiFi check, WiFi Setup system menu item
    On first boot without WiFi, device enters AP mode ('WR-Radio Setup'),
    LCD shows IP address, user connects and configures via browser at 10.42.0.1.
    System menu WiFi Setup allows re-provisioning after relocation.
    [display.py, main.py, wifi.py]
2026-05-30 Fix provisioning screen: replace Korean text with English
    DejaVu font has no Korean glyphs — text rendered as squares.
    All provisioning status messages changed to English.
    [display.py]
2026-05-30 Fix WiFi check race condition on boot
    Wait up to 20s for NetworkManager to connect before entering
    provisioning mode. Prevents false-positive on reboot when NM
    hasn't established WiFi yet.
    [main.py]
2026-05-30 Fix WiFi detection and nmcli privilege issues
    - is_wifi_connected: use 'nmcli device' (TYPE=wifi, STATE=connected)
    instead of 'connection show' which returns TYPE=802-11-wireless
    - All nmcli write commands now use 'sudo nmcli' to work as wr-radio user
    (requires /etc/sudoers.d/wr-radio-nmcli on the device)
    [wifi.py]
2026-05-30 Improve provisioning robustness and LCD feedback
    - _start_hotspot: switch to 'nmcli device wifi hotspot' (simpler, more reliable)
    - provision_wifi: show error on LCD when hotspot fails (was: silent splash)
    - main.py: show 'Connecting to WiFi...' after 3s if WiFi not ready on boot
    - display.py: add display_wifi_waiting() and display_provisioning_error()
    [display.py, main.py, wifi.py]
2026-05-30 Fix provisioning crash loop and connection reliability
    - server.server_close() after shutdown() — socket was left bound,
    causing 'Address already in use' crash on retry, which triggered
    systemd restart and an infinite provisioning loop
    - _connect_to_network: rescan + 3 retries — after stopping hotspot
    wlan0 scan cache is empty, so the first connect often fails to
    find the target SSID
    [wifi.py]
2026-05-30 Clean up hotspot connections by AP mode, not name
    'nmcli device wifi hotspot' auto-names the connection 'Hotspot',
    not our custom name, so the old cleanup never deleted it — leftover
    AP profiles accumulated and could conflict on the next run.
    _cleanup_hotspots() now finds and deletes all AP-mode wifi
    connections regardless of name.
2026-05-30 Fix 'key-mgmt property is missing' connection failure
    'nmcli device wifi connect' needs the target SSID in the current
    scan results to infer the security type. Right after tearing down
    the hotspot the scan cache is empty, so it failed with
    '802-11-wireless-security.key-mgmt: property is missing'.
    Now create the connection profile explicitly with key-mgmt=wpa-psk
    and bring it up — no dependence on scan timing. Clean up stale
    same-named profiles first, and remove a failed profile so it can't
    pollute autoconnect on next boot.
    [wifi.py]
2026-05-30 Add cancel escape to WiFi provisioning (long-press button)
    Provisioning previously had no exit — a wrong password would loop
    forever with only a power cycle to escape. Now holding the button
    for 1.5s cancels: tears down the hotspot (NM auto-reconnects to a
    saved profile) and returns to normal radio mode, which is the
    re-entry point via the system menu. Works in both boot and menu
    contexts. LCD shows 'Hold knob to cancel'.
    [display.py, main.py, wifi.py]
2026-05-30 Skip boot WiFi wait for new devices (no saved profile)
    A configured device may need a few seconds for NetworkManager to
    reconnect on boot, so we wait up to 20s. But a new device has no
    saved profile and will never connect, making the wait pointless.
    has_saved_wifi() lets us skip straight to provisioning in that case.
    [main.py, wifi.py]
2026-05-30 Document WiFi provisioning and nmcli sudoers requirement
    - New 'WiFi Provisioning' section: flow, hotspot/HTTP details, and
    the bugs each design choice fixes (so they aren't regressed)
    - wifi.py added to module list; WiFi Setup added to system menu docs
    - Deployment: per-device sudoers rule for passwordless nmcli (a
    hard requirement — provisioning fails without it)
2026-06-20 Add always-on web UI for station management
    Users can manage the station list (add/edit/delete/reorder) from a
    phone/PC browser at http://<host>.local:8080 instead of SSHing in to
    edit config.json by hand.
    - webadmin.py: new stdlib http.server (port 8080) mirroring wifi.py's
    pattern. GET list+forms, POST add/edit/delete/move. Refuses to delete
    the last station.
    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
2026-06-20 Add place-name geocoding to station web form
    Optional "Place name" field with a Look up button: geocodes via the
    existing OpenWeatherMap key (GET /geocode?q=) and auto-fills lat/lon.
    Manual coordinate entry is unchanged.
2026-06-20 Add Locusonus stream browser to station web UI
    New "Browse Locusonus" page lists the live streams from the Locustream
    Icecast server (status-json.xsl, 5-min cache) with listener counts and
    an Add button per stream. Adding maps server_name -> name, normalizes
    the mount URL to the public https:9443 form, and auto-fills coordinates
    by geocoding the place-name part of the stream name. If geocoding
    fails, it falls back to the manual add form prefilled with name/url so
    the user can enter coordinates by hand. Already-added streams are
    marked. Manual/geocode/DMS entry paths are unchanged.
    [webadmin.py]
2026-06-29 Case modeling
    [av-streamer-led-hat.brd, av-streamer-led-hat.sch, envelope_encoder.step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]
